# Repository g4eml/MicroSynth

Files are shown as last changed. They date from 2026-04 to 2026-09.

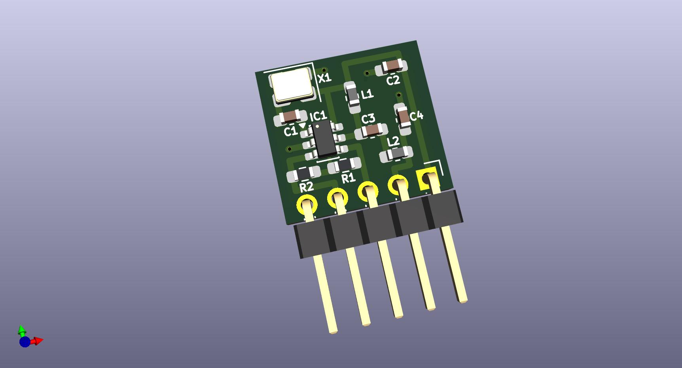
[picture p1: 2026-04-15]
Documents/3D View.jpg

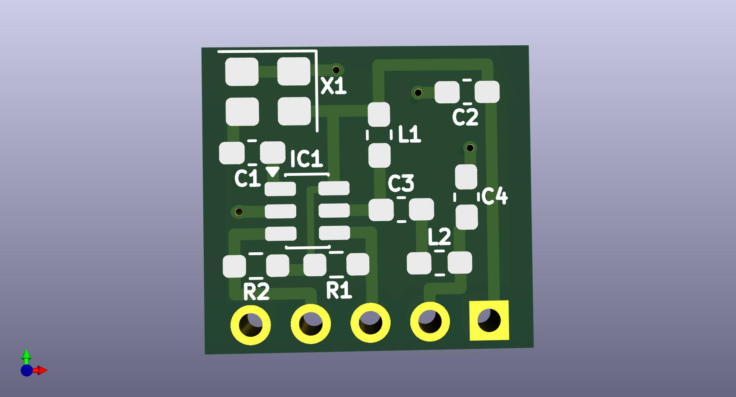
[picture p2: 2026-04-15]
Documents/PCB.jpg

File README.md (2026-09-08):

# MicroSynth
## A Tiny  160 MHz to 1297 MHz RF Synthesiser Module using the CMT2119A Chip.

## Description
The CMT2119A chip is designed as a low cost remote control transmitter operating between 240 and 960 MHz. It is software programmable and has an onboard EEPROM to store its settings. As such it can operate without a separate microcontroller and only needs a 26 MHz reference Crystal and output matching components. 
The datasheet states that the device can be programmed to operate on any frequency between 240 MHz and 960 MHz, some experimenting has shown that in practice this can be extended to aproximately 160MHz and 1297 MHz although this range may vary between chips. Some reverse engineering was done to determine the exact programming sequence needed, this is detailed in this document https://github.com/g4eml/MicroSynth/blob/main/Documents/CMT2119A%20Programming%20Notes.pdf . 

## Construction
Full schematics and PCB design are included in this repository. The CMT2119A devices are available from AliExpress. The NT3225SA 26.000 Mhz TCXO can be found from many suppliers. The remaining components are not critical. 

## Programming

Programming of the CMT2119A chip is done using a RP2040 Zero module which can be created as follows:-

1. Locate the latest compiled firmware file 'MicroSynth.uf2' which will be found here https://github.com/g4eml/MicroSynth/releases and save it to your desktop. 

2. Hold down the BOOTSEL button on the RP2040 module while connecting it to your PC using its USB port. The RP2040 should appear as a USB disk drive on your PC.

3. Copy the .uf2 file onto the USB drive. The RP2040 will recognise the file and immediately update its firmware and reboot.

4. Windows 10 and above should automatically load the necessary driver and allocate a Com Port to the RP2040.

To enter programming mode you need to connect to the USB serial port using a terminal program such as Putty or Terraterm. Pressing any key should result in the menu being displayed.

### Connections for programming

| RP2040 | CMT2119A |
| :---:  |  :---: |
|3V3 | VDD |
|GND | GND |
|GPO6 |  DATA | 
|GPO7 | CLK | 

The Arduino Sketch is also included in this repository if you need to make any changes. 

More comprehensive control of the CMT2119A can also be done by using my RP2040_Synth Programmer which can be found here https://github.com/g4eml/RP2040_Synth .

## Tuning
The matching components may need to be selected for optimum output on your desired frequency according to the table in the schematic. Populating with the 'Wideband' components will work for any frequency but the output will contain harmonics as it is a square wave.
Ouput power in the 'Wideband' configuration ranges from approx +13 dBm at 160 MHz to approx 0dBm at 1296 MHz.

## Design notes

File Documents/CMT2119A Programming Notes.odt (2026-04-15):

CMT2119A Programming Notes.

Serial data format.

Uses a simple 2 wire SPI type interface. No Chip Select. Data line is bidirectional.

Clock is Idle High. Latch Data on the negative going edge.

Data is sent MSB (bit 15) first.

16 bits per transfer.

Bit 15 is always a high.

Bit 14 is low for write and high for read.

Bits 13 to 8 are the register address.

Bits 7 to 0 are the data. Sourced by CPU for Writes and by the CMT2119 for reads.

Max clock rate is 1MHz. (500 ns high 500 ns low)

There are two types of register. The command type uses the above format and appears to configure the chip itself.

The synthesiser settings are programmed into secondary Feature registers which are loaded using a special command sequence.

Programming.

Normally the chip will self program from its built in EEPROM. No external programming is required. The EEPROM is programmed using the manufacturers RFPDK program and USB interface. The exact protocol for this is not documented and currently unknown.

The EEPROM programming can be overridden by a microcontroller using the following procedure, however the settings are not permanent and will be lost on the next power cycle.

The procedure is documented in the datasheet and needs to be followed exactly.

Step 1. Send the special TWI_RESET sequence. This activates the CPU control mode.

Send 32 clock cycles with the data line held low. Then send 0D00. 48 clock cycles in total.

Step 2. Send the Soft Reset Command.

Send 3D01. Then wait at least 1ms.

Step 3. Send an initialisation command (don’t know what it does)

Send 2278.

Step 4. Send a fixed set of commands. (don’t know what they do)

Send 2F80 35CA 36EB 3737 3882

Step 5. Send more commands (don’t know what they do)

Send 1210 1200 2407 1D20

Step 6. Program the Secondary Feature registers. (loop round 21 times)

For each of the 21 Secondary Feature registers. Program the values calculated by the RFPDK program.

Send 18AA to set register address

Send 19LL to set register low 8 bits

Send 1AHH to set register high 8 bits

Send 2501 to program the register

Step 7. Send the TWI_OFF command to end the direct register access.

Send 0D02

RF output is now directly under control of the DATA pin. Low is RF Off. High is RF On.

Secondary registers.

The 21 Secondary register values are best calculated using the RFPDK program. The calculated values can be output to a text file using the Export function.

The register functions are not documented but the following has been found by reverse engineering and can be used for live tuning.

Register 0:- Normal Value = 5000 5400 enables a /2 output divider for lower output frequencies.

Register 6:- Normal Value = 0000 0001 enables a /1.5 output divider for lower frequencies

Register 7:- Holds the low 16 bits of the fractional N divider. Bit zero is always low so N must always be even.

Register 8:- Bits 15 to 8 hold the top 8 bits of the fractional N divider. Bit 7 is high for FSK mod low for OOK mod.

Register 9:- Bits 10 to 3 hold the deviation setting (FSK Shift) for FSK mode. (Zero for OOK)

Frequency Calculation.

Frequency 240 – 320 MHz Output divider = 3 (1.5 and 2.0)

Frequency 320 – 480 MHz Output Divider = 2

Frequency 480 – 640 MHz Output Divider = 1.5

Frequency 640 – 960 MHz Output Divider = 1

Reference frequency = 26 MHz.

Step size = 26000000 / 2^17 = 198.3642578125 Hz.

VCO Frequency = Output Frequency * Output Divider.

Divider setting = VCO Frequency / Step Size

Divider must be even. So step size is effectively doubled.

Examples.

250.0 MHz Output Divider = 3 VCO = 750.0 Divider = 3780922 = 39B13A Hex

435.0 MHz Output Divider = 2 VCO = 870.0 Divider = 4385870 = 42EC4E Hex

500.0 MHz Output Divider = 1.5 VCO = 750.0 Divider = 3780922 = 39B13A Hex

800.0 MHz Output Divider = 1 VCO = 800.0 Divider = 4032984 = 3D89D8 Hex

Programming the device EEPROM

Reverse engineered procedure for programming the device EEPROM.

Step 1. Send the special TWI_RESET sequence. This activates the CPU control mode.

Send 32 clock cycles with the data line held low. Then send 0D00. 48 clock cycles in total.

Step 2. Send the special power on sequence (don’t know exactly what this does)

Send 023B 2F80 3F01 1631 35CA 36EB 3737 3882

Step 3. Erase each EEPROM Location and then write new value. (repeat for each location)

Send 17AA to set EEPROM address

Send 1639 to start the Erase

wait 1 ms then Read Register 1F until it returns with bit 3 =1

Send 1631 to end the Erase

Send 17AA to reset EEPROM address

Send 19LL to set the low 8 bits

Send 1AHH to set the high 8 bits

Send 1635 to start the EEPROM Write

wait 1 ms then Read Register 1F until it returns with bit 3 =1

Send 1631 to end the Write

Step 4. Send the Exit Sequence

Send 1630 3F00 0C27 2F00 027F 0C07 3D01

Optional EEPROM verify

The Factory Programmer also verifies the EEPROM values

Step 1. Send the special TWI_RESET sequence. This activates the CPU control mode.

Send 32 clock cycles with the data line held low. Then send 0D00. 48 clock cycles in total.

Step 2. Send the special power on sequence (don’t know exactly what this does)

Send 023B 2F80 3F01 1631 35CA 36EB 3737 3882

Step 3. Read and verify each EEPROm Location (repeat for each location)

Send 17AA to set the EEPROM Address

Send 1633 to read the EEPROM

wait 1 ms then Read Register 1F until it returns with bit 3 =1

Read Register 1B for the EEPROM Low Byte

Read Register 1C for the EEPROM High Byte

Send 1631 to end the read

Step 4. Send the Exit Sequence

Send 1630 3F00 0C27 2F00 027F 0C07 3D01

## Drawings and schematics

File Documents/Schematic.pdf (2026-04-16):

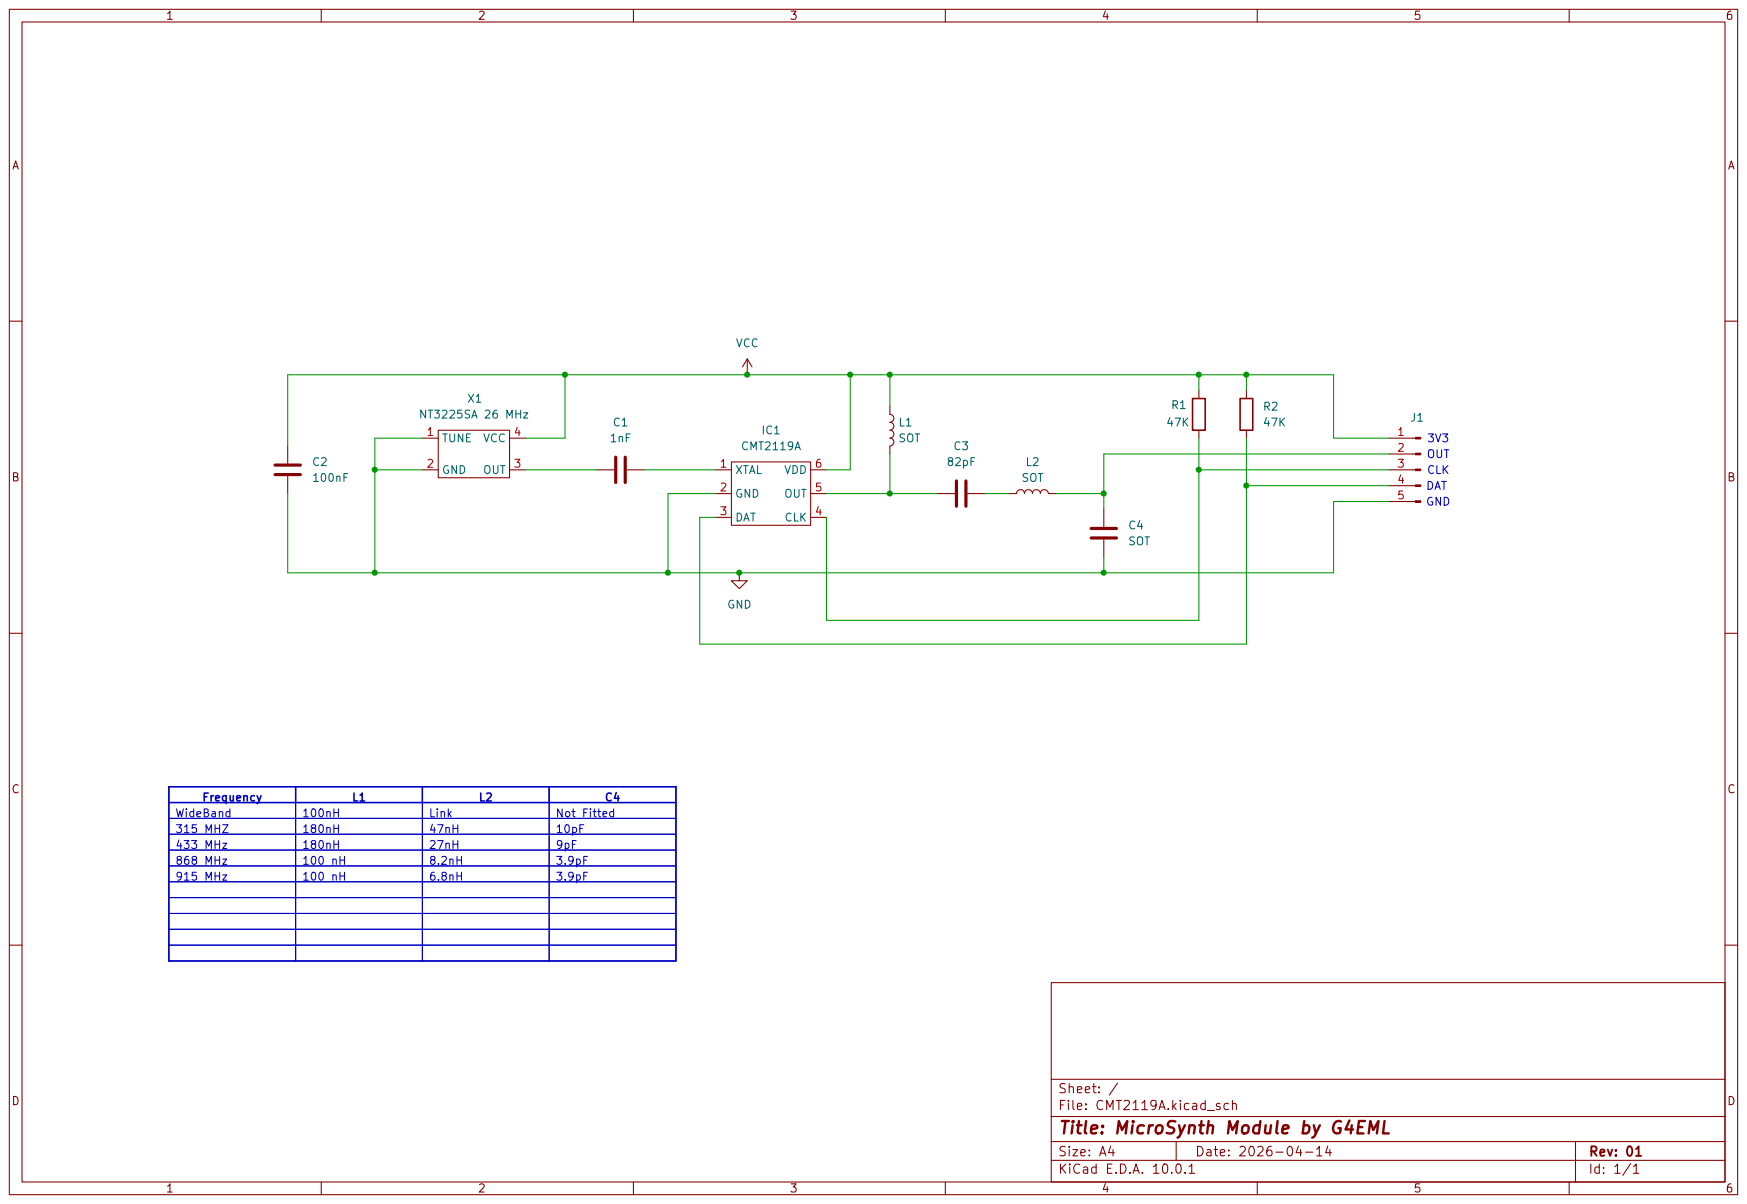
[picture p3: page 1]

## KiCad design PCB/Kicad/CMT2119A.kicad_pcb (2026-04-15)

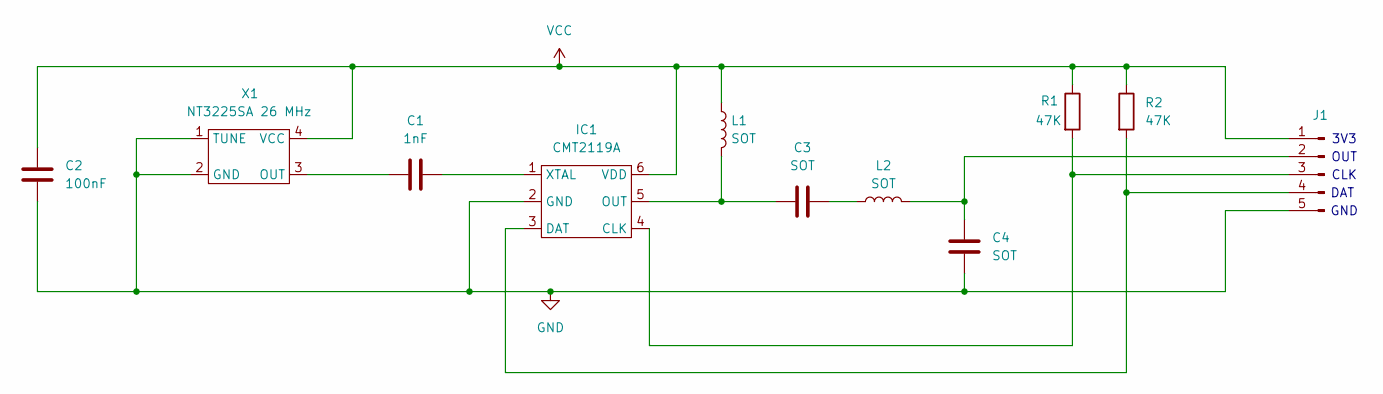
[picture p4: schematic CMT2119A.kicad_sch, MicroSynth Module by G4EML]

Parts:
C1: 1nF; C_0805_2012Metric
C2: 100nF; C_0805_2012Metric
C3, C4: SOT; C_0805_2012Metric
IC1: CMT2119A; SOT-23-6
J1: Conn_01x05_Pin; PinHeader_1x05_P2.54mm_Vertical
L1, L2: SOT; L_0805_2012Metric
R1, R2: 47K; R_0805_2012Metric
X1: NT3225SA 26 MHz; Crystal_SMD_3225-4Pin_3.2x2.5mm

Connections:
GND: C2.2, C4.2, IC1.2 (GND), J1.5, X1.1 (TUNE), X1.2 (GND)
unnamed: C3.2, L2.1
unnamed: IC1.4 (CLK), J1.3, R1.2
unnamed: IC1.3 (DAT), J1.4, R2.2
unnamed: C3.1, IC1.5 (OUT), L1.2
unnamed: C1.2, IC1.1 (XTAL)
unnamed: C4.1, J1.2, L2.2
unnamed: C1.1, X1.3 (OUT)
VCC: C2.1, IC1.6 (VDD), J1.1, L1.1, R1.1, R2.1, X1.4 (VCC)

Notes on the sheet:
CLK
3V3
DAT
OUT
GND

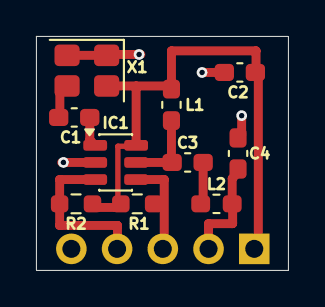
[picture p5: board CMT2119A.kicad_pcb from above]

Board: 2 copper layers, 14.0 x 13.0 mm, 11 parts (0 on the bottom side), 9 nets.

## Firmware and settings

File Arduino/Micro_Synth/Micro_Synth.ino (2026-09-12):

// Micro_Synth - CMT2119A Synthesiser controller using RP2040
//
// Minimal single-chip frequency programmer for the CMT2119A: Set Reference
// Oscillator, Enter Output Frequency, Calculate Frequency, and Program
// CMT2119A (burn to the chip's own EEPROM). No channels, no external
// multiplier, no raw register inspection, and no RP2040-side settings
// storage - the CMT2119A's own EEPROM (via the "Program CMT2119A" menu
// option) is this project's only persistence.

#define VERSION 1.10

uint32_t cmtReg[21];      //the CMT2119A's 21 registers (single set - no channels)

double refOsc = 26.000;   //reference oscillator frequency in MHz

#include "Pio_WS2812.pio.h"               //LED on the Rp2040-Zero

void setup()
{
  setup_Pio_WS2812(16);                 //Setup LED on Rp2040-Zero
  put_pixel(GREEN);
  Serial.begin();                       //USB serial port

  delay(1000);
  cmtInit();
  cmtSetDefault();                      //load the chip's default registers.
}

void loop()
{
  Serial.print("\n");
  Serial.print("CMT2119A Synthesiser programmer. Press Any Key for Menu.");
  Serial.println();

  while(1)
   {
      if(Serial.available() > 0 )          //test for USB command connected
     {
       put_pixel(BLUE);                   //BLUE = menu active
       mainMenu();                         //timing loop stops while the menu system is running.
       delay(10);
       put_pixel(GREEN);                    // Menu Exited
       cmtUpdate();
       Serial.print("\nSynthesiser programmed. Press any key for menu");
       delay(500);
       flushInput();
     }

   }

}

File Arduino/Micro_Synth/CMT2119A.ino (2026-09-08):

//Chip specific functions for the CMT2119A device.
//
//This is the only chip driver in this project. There is a single, flat set of
//21 registers (cmtReg[]) - no channels, no external multiplier, no register
//inspection menu. All FSK/modulation related methods (fskKey, extKey, jtShift,
//saveFskShift, saveKeyShift, saveJt) have also been removed, since this build
//only does straightforward frequency programming.

#define TWICLK 6         //GPO 6 Connect to CMT2119A  CLK Pin
#define TWIDAT 7         //GPO 7 Connect to CMT2119A  DAT Pin


#define CMTNUMREGS 21     //number of registers in the CMT2119A
#define CMTMAXOSC 30      //maximum reference oscillator frequency (MHz)
#define CMTMINOSC 20      //minimum reference oscillator frequency (MHz)

// A default register setting for a starting point. Generated by Official programming software.
static const uint16_t CMT2119ook[CMTNUMREGS] =
{
0x007F,
0x5000,
0x0000,
0x0000,
0x0000,
0xF000,
0x0000,
0xBB13,
0x4200,
0x0000,
0x2401,
0x01B0,
0x8000,
0x0006,
0xFFFF,
0x0020,
0x5F1E,
0x22D6,
0x0E13,
0x0019,
0x2000,
};

void cmtSetDefault(void)
{
  for(int i = 0;i<CMTNUMREGS;i++)
  {
    cmtReg[i] = CMT2119ook[i];
  }
}

void cmtInit(void)
{
  pinMode(TWICLK,OUTPUT);
  digitalWrite(TWICLK,HIGH);
  pinMode(TWIDAT,OUTPUT);
  digitalWrite(TWIDAT,HIGH);            //TWIDAT left high as this enables the output. 
}

void CMT2119A_RESET(void)
{
  TWI_reset(); //step 1
  TWI_WRREG(0x3d, 0x01); //step 2 send SOFT_RST
  delay(2);
  TWI_WRREG(0x0D, 0x02); //step 7 send the TWI_OFF command. Control reverts to simple DAT signals
}


void cmtUpdate(void)
{
TWI_reset(); //step 1
TWI_WRREG(0x3d, 0x01); //step 2 send SOFT_RST
delay(2);

//some proprietary command preamble from the datasheet
TWI_WRREG(0x02, 0x78); //Open LDO & Osc step 3

TWI_WRREG(0x2F, 0x80); //vActiveRegsister step 4
TWI_WRREG(0x35, 0xCA);
TWI_WRREG(0x36, 0xEB);
TWI_WRREG(0x37, 0x37);
TWI_WRREG(0x38, 0x82);

TWI_WRREG(0x12, 0x10); //vEnableRegMode step 5
TWI_WRREG(0x12, 0x00);
TWI_WRREG(0x24, 0x07);
TWI_WRREG(0x1D, 0x20);

//program the RAM config
for(int i =0;i<CMTNUMREGS;i++)
 {
  TWI_RAM1(i,cmtReg[i]);
 }

TWI_WRREG(0x0D, 0x02); //step 7 send the TWI_OFF command. Control reverts to simple DAT signals

digitalWrite(TWIDAT,HIGH);                 //output on
delay(2);
}


//Reads the CMT2119A's own on-chip EEPROM back into cmtReg[], so a chip that
//was already programmed (its EEPROM burned, e.g. via 'P' on this or another
//unit) can have its settings read into this programmer. This reuses the same
//TWI_EEPROM_SETUP()/TWI_EEPROM_READ()/TWI_EEPROM_END() sequence that
//cmtEepromBurn() already uses to verify its own writes, rather than
//inventing a new, unverified RAM-register read protocol.
void cmtReadFromChip(void)
{
  TWI_reset();
  TWI_reset();
  TWI_EEPROM_SETUP();
  for(int r=0;r<0x15;r++)           //read EEPROM values 0x00 - 0x14
   {
    cmtReg[r] = TWI_EEPROM_READ(r);
   }

uint16_t bytes[4];            //for reading in the Ref Oscillator value

  for(int r=0x15;r<0x19;r++)           //read EEPROM values 0x15 - 0x18
   {
    bytes[r-0x15] = TWI_EEPROM_READ(r);
   }

   memcpy(&refOsc, bytes, sizeof(refOsc));

   if((refOsc < 25.00) | (refOsc > 27.00))
    {
      Serial.println("Setting Default Ref Osc = 26 MHz");
      refOsc = 26.00;
    }

  TWI_EEPROM_END();

  Serial.println("Resetting from CMT2119A EEPROM");
  CMT2119A_RESET();
  digitalWrite(TWIDAT,HIGH);
}


double cmtGetPfd(void)
{
  double pfd = refOsc / 131072.0 ;
  return pfd;
}

void cmtSetFrequency(double direct)
{
  bool freqOK = false;

  double freq;
  double pfd;
  uint8_t prescale15;
  uint8_t prescale2;

  pfd = cmtGetPfd();

  freqOK = false;
  if(direct ==0)
  {
   while(!freqOK)
    {
      Serial.print("\nEnter Required Frequency in MHz -->");
      freq = inputFloat();
      if((freq > 150.0) && (freq <= 1297.0))
        {
          freqOK = true;
        }
      else
        {
          Serial.println("Synthesiser Frequency must be between 150 and 1297 MHz");
        }
    }
  }
  else
  {
    freq = direct;
  }

if(freq<=320.0)
	{
	prescale15=1;
	prescale2=1;
	}
else if(freq<=480.0)
	{
	prescale15=0;
	prescale2=1;
	}
else if(freq<=640.0)
        {
        prescale15=1;
        prescale2=0;
        }
else
	{
	prescale15=0;
        prescale2=0;
	}

if(prescale15) cmtReg[6] = 1; else cmtReg[6] = 0;
if(prescale2) cmtReg[1] = 0x5400; else cmtReg[1] = 0x5000;

if(prescale15) freq = freq * 1.5;
if(prescale2) freq = freq *2.0;

//frequency
uint32_t pll = round((freq/pfd)/2) *2;                //round to nearest even number
cmtReg[7] = pll & 0xfffe;              //lsb must always be zero.
uint16_t pllh = (pll >> 8) & 0xFF00;
cmtReg[8] = pllh;
cmtReg[9] = 0;
}


void cmtCalcFreq(void)
{
 uint8_t prescale15;
 uint8_t prescale2;
 uint32_t divider;
 double vco;
 double pfd;
 double diva;

 prescale15 = cmtReg[6] & 0x01;
 prescale2 = (cmtReg[1] & 0x0400) >> 10;
 divider = ((cmtReg[8] & 0xFF00) << 8) + cmtReg[7];
 pfd = cmtGetPfd();

 vco = (double) divider * pfd;
 diva=1;
 if(prescale2) diva = diva * 2;
 if(prescale15) diva=diva * 1.5;


  Serial.println();
  Serial.print("Chip type is CMT2119A");
  Serial.println();
  Serial.print("Reference Oscillator = ");
  Serial.print(refOsc,10);
  Serial.println(" MHz");
  Serial.print("Step Size = ");
  Serial.print(pfd*2000000,10);           //double the step size to allow for the fact the divider must be even.
  Serial.println(" Hz");
  Serial.print("N = ");
  Serial.println(divider/2);              //halve the divider to allow for the fact it must be even.

  Serial.print("VCO = ");
  Serial.print(vco , 10);
  Serial.println(" MHz");

  Serial.print("O/P Divider = ");
  Serial.println(diva,1);

  Serial.print("Output Frequency = ");
  Serial.print(vco / diva , 10);
  Serial.println(" MHz");
}

double cmtGetFrequency(void)
{
 uint8_t prescale15;
 uint8_t prescale2;
 uint32_t divider;
 double vco;
 double pfd;
 double diva;

 prescale15 = cmtReg[6] & 0x01;
 prescale2 = (cmtReg[1] & 0x0400) >> 10;
 divider = ((cmtReg[8] & 0xFF00) << 8) + cmtReg[7];
 pfd = cmtGetPfd();

 vco = (double) divider * pfd;
 diva=1;
 if(prescale2) diva = diva * 2;
 if(prescale15) diva=diva * 1.5;

 return vco/diva;
}


void TWI_reset(void)
{
digitalWrite(TWIDAT,LOW);
digitalWrite(TWICLK,HIGH);
delayMicroseconds(1);

for(uint8_t i=0; i<32; ++i)
	{
	  digitalWrite(TWICLK,LOW);
	  delayMicroseconds(1);
	  digitalWrite(TWICLK,HIGH);
    delayMicroseconds(1);
	}
  TWI_WRREG(0x0d, 0x00);
}


void TWI_Write(uint8_t x)
{
digitalWrite(TWICLK,HIGH);
digitalWrite(TWIDAT,LOW);
for(uint8_t i=0; i<8; ++i)
	{
	digitalWrite(TWICLK,HIGH);
	if(x & 0x80) digitalWrite(TWIDAT,HIGH); else digitalWrite(TWIDAT,LOW);
	delayMicroseconds(1);
  digitalWrite(TWICLK,LOW);
	delayMicroseconds(1);
	x<<=1;
	}
	digitalWrite(TWICLK,HIGH);
  digitalWrite(TWIDAT,LOW);
}
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

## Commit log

2026-09-08 Revise programming section in README.md
    Updated programming instructions for the CMT2119A chip using the RP2040 module. Added steps for firmware installation and included a reference to the Arduino Sketch.
2026-09-08 Update README with Windows driver and connection info
    Added instructions for Windows driver installation and programming connections.
2026-09-08 Save Ref Oscillator frequency to EEPROM
    [CMT2119A.ino, Menu.ino]
